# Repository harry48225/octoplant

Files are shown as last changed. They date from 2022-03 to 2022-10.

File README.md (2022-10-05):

# octoplant
Plant water indicator

octoplant helps you keep your plant hydrated. Using 12 LEDs it shows the current soil moisture level and allows you to set the water point so you can easily see how far off you are from the moisture level at which you normally water.

It's designed around an attiny824. A custom PCB combines it along with 12 LEDs, a wide trace that acts as a capacitive moisture sensor, a button, and a cr2032 battery (holder).

Simply press the button to light the leds. The soil moisture level is measured and then compared to the calibrated wet and dry points. By holding down the button you can save a moisture level and this led will blink on all further readings (I like to use this to save the level of moisture I usually water at). 

Built with:
 - Arduino (TinyMega core)
 - kicad
 - platform io
 
 [More info on hackaday](https://hackaday.io/project/187372/details/)

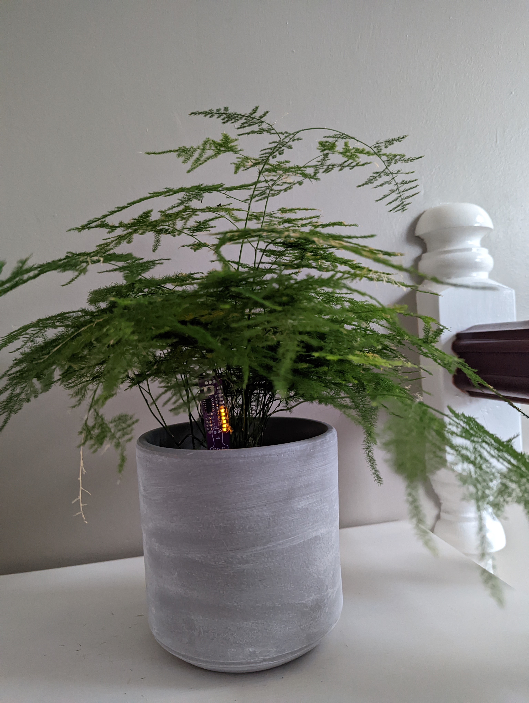
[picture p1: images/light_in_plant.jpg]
octoplant in an aparagus fern


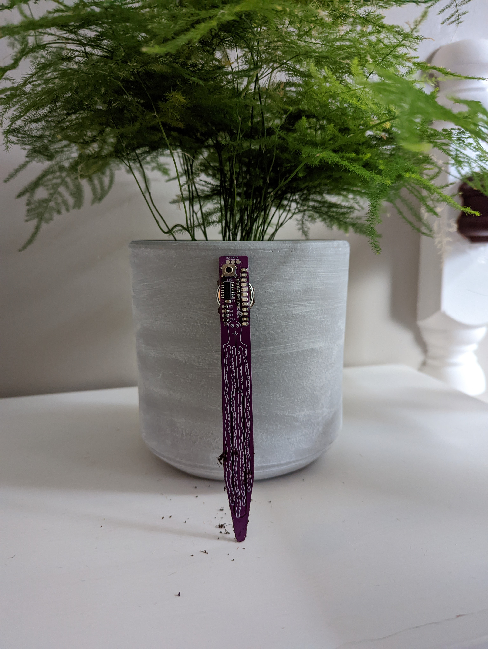
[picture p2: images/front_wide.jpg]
octoplant front wide


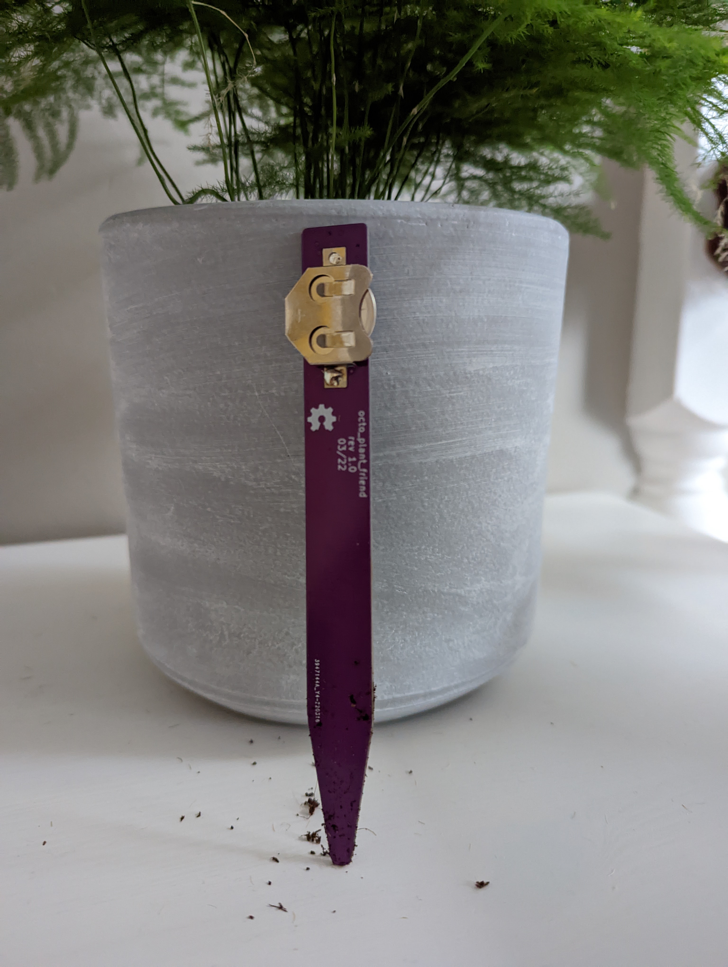
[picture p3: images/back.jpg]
octoplant back wide


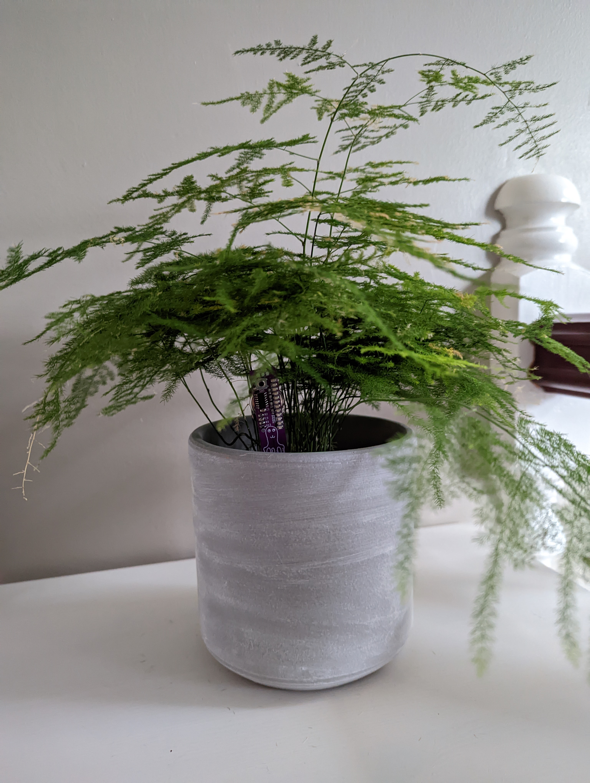
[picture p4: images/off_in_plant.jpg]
octoplant front wide off


octoplant front close

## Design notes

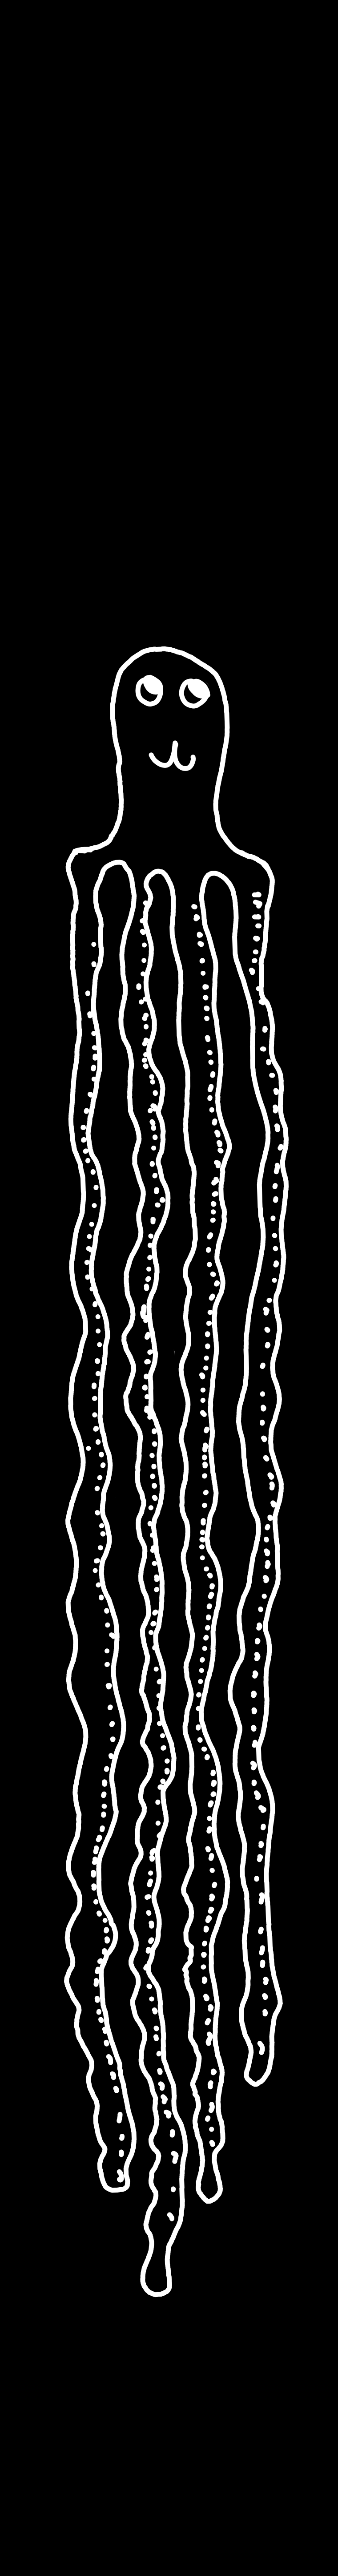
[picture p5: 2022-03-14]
pcb/art/octoplant.png

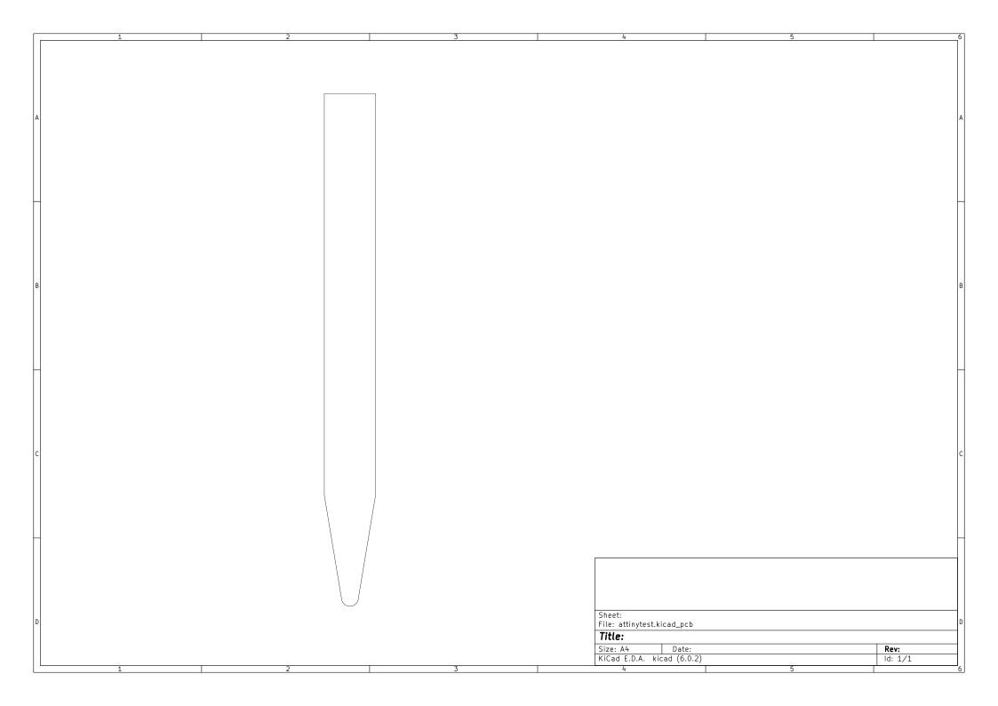
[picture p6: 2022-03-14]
pcb/octoplant.png

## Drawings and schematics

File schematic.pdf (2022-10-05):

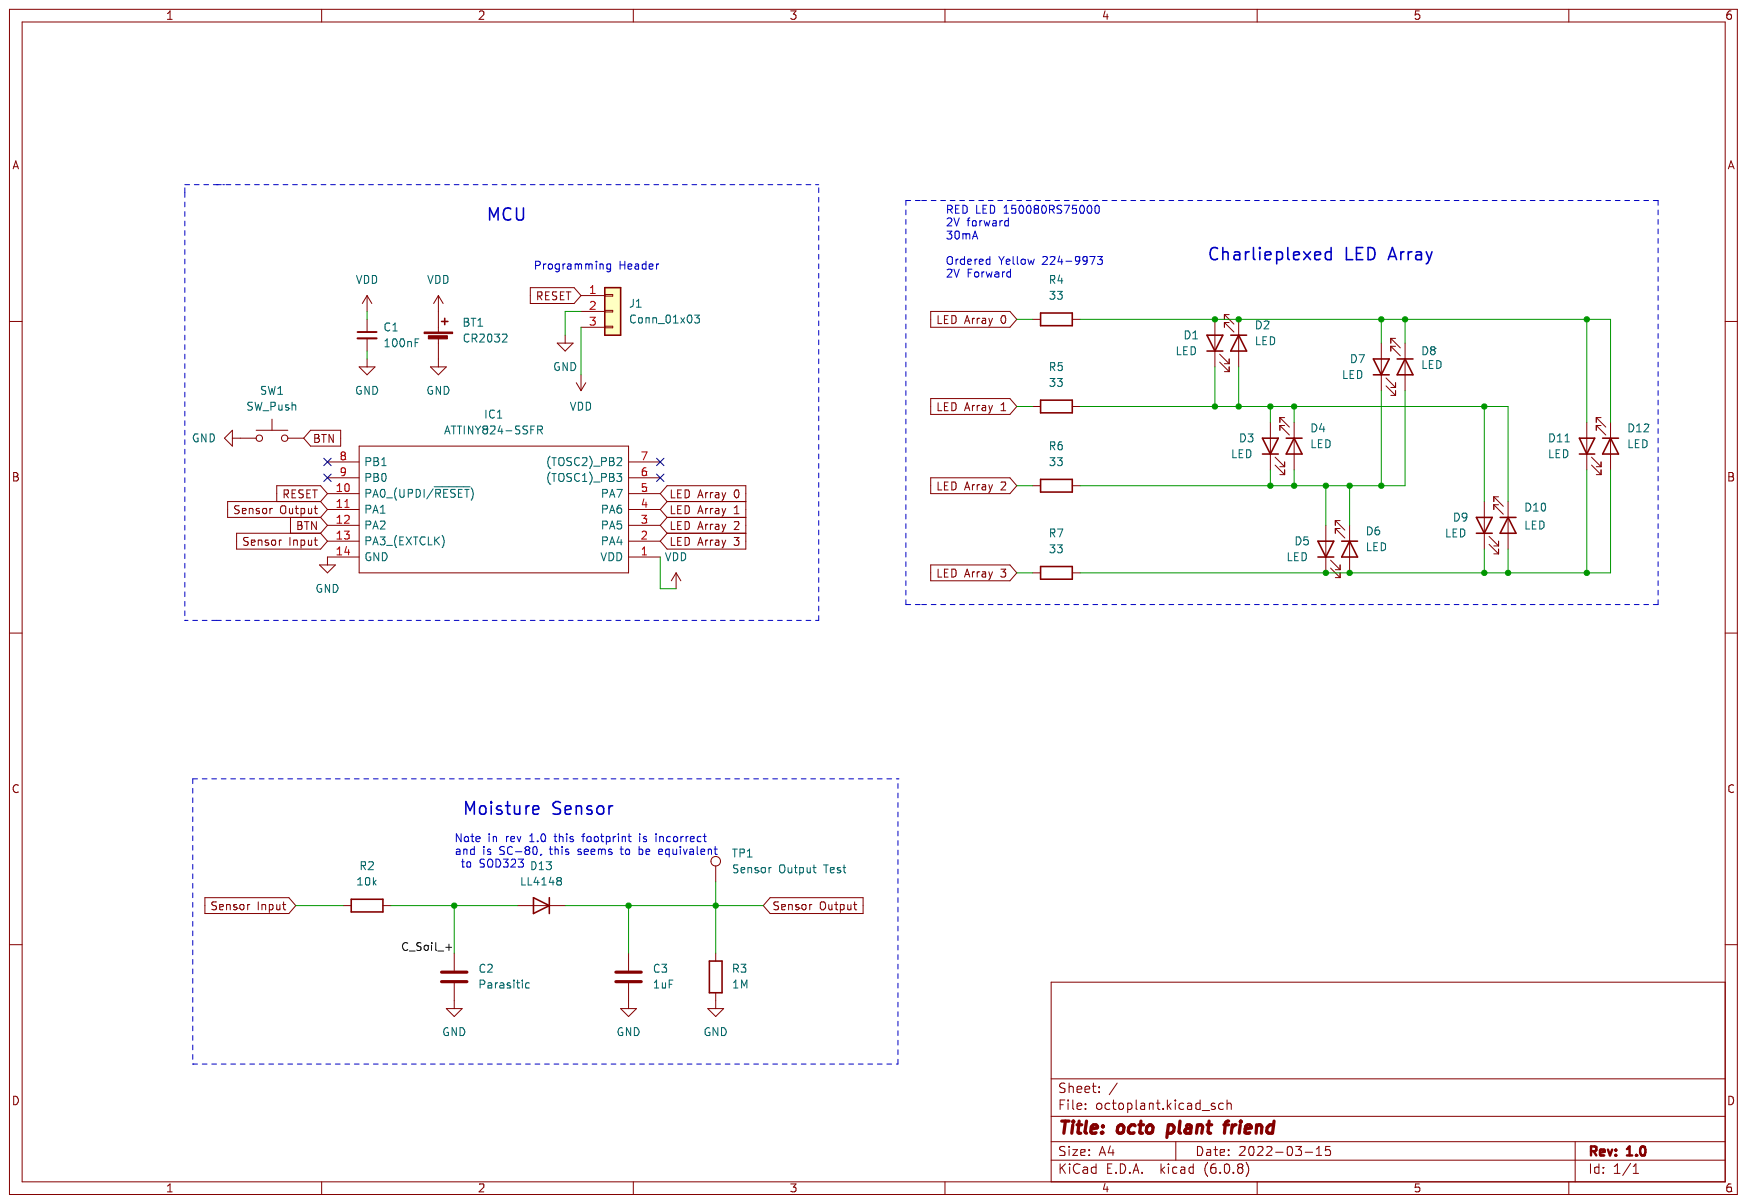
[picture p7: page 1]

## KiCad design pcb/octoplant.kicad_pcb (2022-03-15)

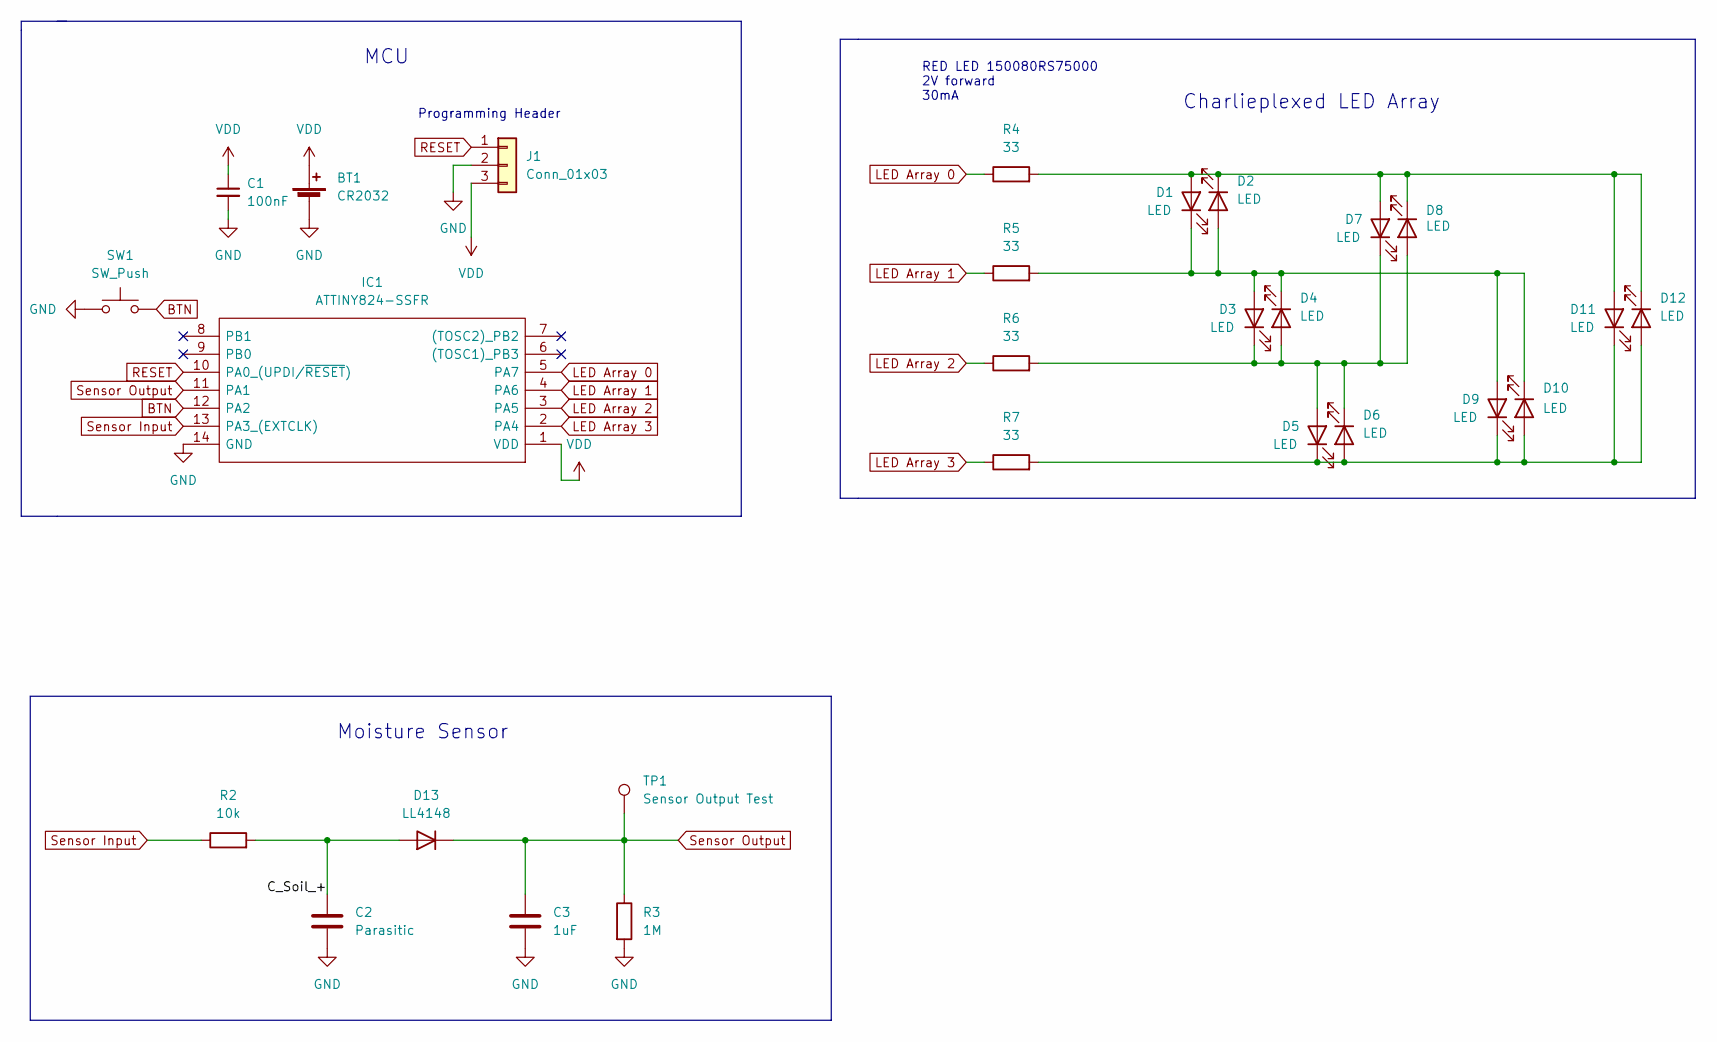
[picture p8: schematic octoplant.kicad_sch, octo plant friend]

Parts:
BT1: CR2032; BatteryHolder_Keystone_3002_1x2032
C1: 100nF; C_0805_2012Metric_Pad1.18x1.45mm_HandSolder
C2: Parasitic; soilCapactiorTrace
C3: 1uF; C_0805_2012Metric_Pad1.18x1.45mm_HandSolder
D1, D2, D3, D4, D5, D6, D7, D8, D9, D10, D11, D12: LED; LED_0805_2012Metric_Pad1.15x1.40mm_HandSolder
D13: LL4148; D_SC-80_HandSoldering
IC1: ATTINY824-SSFR; SOIC-14_3.9x8.7mm_P1.27mm; Manufacturer_Part_Number ATTINY824-SSFR; Mouser Part Number 579-ATTINY824-SSFR
J1: Conn_01x03; TestPoint_Pad_3x1_D1.5mm
R2: 10k; R_0805_2012Metric_Pad1.20x1.40mm_HandSolder
R3: 1M; R_0805_2012Metric_Pad1.20x1.40mm_HandSolder
R4, R5, R6, R7: 33; R_0805_2012Metric_Pad1.20x1.40mm_HandSolder
SW1: SW_Push; SW_Push_1P1T_NO_CK_KSC6xxJ
TP1: Sensor Output Test; TestPoint_Pad_D1.5mm

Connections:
/C_Soil_+: C2.1, D13.2 (A), R2.2
BTN: IC1.12 (PA2), SW1.2
GND: BT1.2 (-), C1.2, C2.2, C3.2, IC1.14 (GND), J1.2, R3.2, SW1.1
LED Array 0: IC1.5 (PA7), R4.1
LED Array 1: IC1.4 (PA6), R5.1
LED Array 2: IC1.3 (PA5), R6.1
LED Array 3: IC1.2 (PA4), R7.1
unnamed: D1.1 (K), D2.2 (A), D3.2 (A), D4.1 (K), D9.2 (A), D10.1 (K), R5.2
unnamed: D1.2 (A), D2.1 (K), D7.2 (A), D8.1 (K), D11.2 (A), D12.1 (K), R4.2
unnamed: D3.1 (K), D4.2 (A), D5.2 (A), D6.1 (K), D7.1 (K), D8.2 (A), R6.2
unnamed: D5.1 (K), D6.2 (A), D9.1 (K), D10.2 (A), D11.1 (K), D12.2 (A), R7.2
RESET: IC1.10 (PA0_(UPDI/~RESET)), J1.1
Sensor Input: IC1.13 (PA3_(EXTCLK)), R2.1
Sensor Output: C3.1, D13.1 (K), IC1.11 (PA1), R3.1, TP1.1
VDD: BT1.1 (+), C1.1, IC1.1 (VDD), J1.3

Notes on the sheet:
RED LED 150080RS75000 2V forward 30mA
Charlieplexed LED Array
Programming Header
Moisture Sensor
MCU

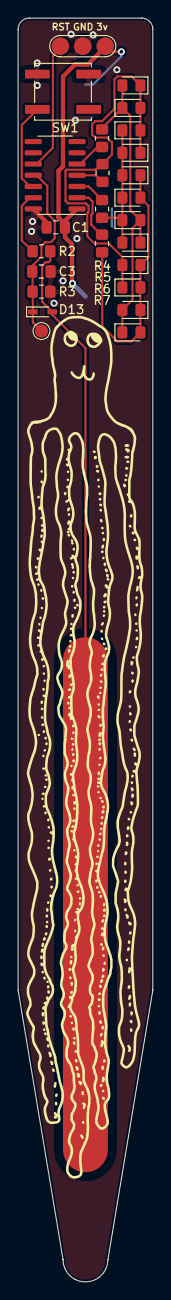
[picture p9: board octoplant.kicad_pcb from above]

Board: 2 copper layers, 15.2 x 143.0 mm, 27 parts (1 on the bottom side), 15 nets.

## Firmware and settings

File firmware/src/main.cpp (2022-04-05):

#include <Arduino.h>
#include "LedManager.h"
#include "MoistureManager.h"
#include "SleepManager.h"
#include "ConfigManager.h"
#include <avr/sleep.h>
#include "Constants.h"

#ifndef MILLIS_USE_TIMERB1
  #error "This sketch is written for use with TCB1 as the millis timing source"
#endif

long startTime = 0;

long buttonPressTime = 0;

void setup() {
  takeOverTCA0();
  TCA0.SPLIT.CTRLD = 0x01; // Enable split mode  
  
  LedManager::setup();
  MoistureManager::setup();
  SleepManager::setup();

  TCA0.SPLIT.CTRLA = TCA_SPLIT_ENABLE_bm | TCA_SPLIT_CLKSEL_DIV64_gc; //enable the timer 64 prescaler
  delay(100);
  ConfigManager::loadConfig();

  delay(250); // Wait for moisture reading to stabilise

  pinMode(BUTTON_PIN, INPUT_PULLUP);

  startTime = millis();
}

void loop() {
  byte buttonIsPressed = digitalRead(BUTTON_PIN) == LOW;

  if ((millis()-startTime) > KEEP_AWAKE_TIME_MS && !buttonIsPressed) {
    SleepManager::sleep();
  }

  if (buttonIsPressed) {
    if (buttonPressTime == 0) {
      buttonPressTime = millis();
    } else if ((millis() - buttonPressTime) > WATER_POINT_SETTING_WAIT_MS) {
      ConfigManager::setWaterPoint();
      startTime = millis();
    }
  } else {
    buttonPressTime = 0;
  }

  int moisture = MoistureManager::getNormalisedReading();
  for (int i = 0; i < 12; i++) {
    if ((12-i) == ConfigManager::NORMALISED_WATER_POINT) {
      LedManager::flashLed(i, LedManager::FlashRate::SLOW);
    } else if ((12-i) <= moisture) {
      LedManager::turnOnLed(i);
    } else {
      LedManager::turnOffLed(i);
    }
  }
  delay(100);
}

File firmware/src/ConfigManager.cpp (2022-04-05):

#include "ConfigManager.h"

#include <EEPROM.h>
#include <LedManager.h>
#include <Arduino.h>
#include "MoistureManager.h"
#include "Constants.h"

// Handles storing data in the EEPROM
// MAP
#define DRY_POINT_ADDR 0
#define WET_POINT_ADDR 2
#define NORMALISED_WATER_POINT_ADDR 4

namespace ConfigManager {
  int DRY_POINT;// = 3200;
  int WET_POINT;// = 1500;
  int NORMALISED_WATER_POINT;// = 3;

  void programSuccessfulAnimation() {
    LedManager::resetLeds();

    // Display programming animation
    for (int i = 0; i <= 6; i++) {
      LedManager::turnOnLed(6-i);
      LedManager::turnOnLed(5+i);
      delay(20);
    }

    LedManager::resetLeds();

    delay(200);
  }

  void waitForButtonRelease() {
    while (digitalRead(BUTTON_PIN) == LOW) {
      delay(10);
    }
  }

  void waitForButtonPress() {
    while (digitalRead(BUTTON_PIN) == HIGH) {
      delay(10);
    }
  }

  void setWaterPoint() {
    // Set the water point as the current normalised water reading
    // Should be triggered on long press
    NORMALISED_WATER_POINT = MoistureManager::getNormalisedReading();
    LedManager::flashLed(12-NORMALISED_WATER_POINT, LedManager::FlashRate::FAST);
    waitForButtonRelease();
    delay(200);
    writeConfig();
    programSuccessfulAnimation();
  }

  void calibrate() {
    // Enable button
    pinMode(BUTTON_PIN, INPUT_PULLUP);
    
    // Set the wet point
    // Flash all leds
    for (int i = 0; i < 12; i++) {
      LedManager::flashLed(i, LedManager::FlashRate::FAST);
    }

    waitForButtonRelease();
    waitForButtonPress();
    WET_POINT = MoistureManager::getRawReading() + 100;
    LedManager::resetLeds();
    waitForButtonRelease();
    
    // Set the dry point  
    // Flash the lowest LED
    LedManager::flashLed(11, LedManager::FlashRate::FAST);
    waitForButtonPress();
    DRY_POINT = MoistureManager::getRawReading() - 100;
    waitForButtonRelease();
    writeConfig();

    programSuccessfulAnimation();
  }

  void loadConfig() {
    // First determine the reset cause

    byte isPowerOnReset = 0;
    // Megatinycore stores the reset flags in GPIO0 and automatically clears them
    byte reset_flags = GPIO0;
    // If it's not a software reset we may want to enter calibration mode
    if (reset_flags & RSTCTRL_PORF_bm) {
      isPowerOnReset = 1;
    }

    // Reads the configuration from EEPROM
    EEPROM.get(DRY_POINT_ADDR, DRY_POINT);
    EEPROM.get(WET_POINT_ADDR, WET_POINT);

    EEPROM.get(NORMALISED_WATER_POINT_ADDR, NORMALISED_WATER_POINT);

    // Enable button
    pinMode(BUTTON_PIN, INPUT_PULLUP);

    // Calibrate if the eeprom is not configured
    // or if the button is held and we've just powered on
    // If it's not configured the EEPROM contains 0xFF in each location
    if ((DRY_POINT == 0xFFFF && WET_POINT == 0xFFFF) || (digitalRead(BUTTON_PIN) == LOW && isPowerOnReset)) {
      calibrate();
    }
  }

  void writeConfig() {
    EEPROM.put(DRY_POINT_ADDR, DRY_POINT);
    EEPROM.put(WET_POINT_ADDR, WET_POINT);
    EEPROM.put(NORMALISED_WATER_POINT_ADDR, NORMALISED_WATER_POINT);
  }
}

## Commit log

2022-03-14 Add silkscreen art
    [octoplant.kicad_pcb]
2022-03-14 Change button pin to a fully async one
    [octoplant.kicad_pcb, octoplant.kicad_sch]
2022-03-15 resize capacitor pad
    [octoplant.kicad_pcb, octoplant.kicad_sch]
2022-03-15 Finalise pcb
    [octoplant.kicad_pcb]
2022-04-03 Tweak pcb
    [octoplant.kicad_sch]
2022-04-03 Add led helper methods
2022-04-03 Basic button test
2022-04-04 Increase led frequency
2022-04-04 Add led flashing
2022-04-04 Refactor led flashing
2022-04-04 Add calibration
2022-04-04 Add ability to enter calibration mode
2022-04-04 Refactor calibration code
2022-04-04 Only enter calibration mode on powerup
2022-04-05 Add delay to stabilise moisture readnig
    [main.cpp]
2022-10-05 add schematic
    [octoplant.kicad_sch]
